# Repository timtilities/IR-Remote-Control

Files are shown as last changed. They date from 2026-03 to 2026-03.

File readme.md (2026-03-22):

I have a *Hunter* space heater whose remote control had partially stopped working. The power and mode buttons no longer functioned. Rather than buying a new heater, I decided to take a crack at making a new remote control for it.

***

Some of the buttons still worked, so I setup a [simple IR receiver](https://github.com/Arduino-IRremote/Arduino-IRremote/blob/master/examples/ReceiveDemo/ReceiveDemo.ino) with an Arduino Nano to scan the working button codes. 

The design uses the ATTINY85 MCU and a matrix keypad with 12 buttons (although only 6 are in use for this).  Each button press fires an interrupt to wake the MCU and send the IR signal associated with the button. Once that completes, the MCU goes back into deep sleep. The circuit uses around 30mA while sending and <10nA when sleeping. Assuming 10 button presses per day (over only the winter months), the 2 AAA batteries *should* last more than [5 years](http://oregonembedded.com/batterycalc.htm).  I use NiMH rechargeable batteries removed at the end of each season, so if I have to recharge them once a year I'm happy.

Since I rarely order single PCBs, I designed it with 12 buttons to allow the PCBs to be used in future projects.

The battery clips are Keystone Electronics [55TR](https://www.keyelco.com/product.cfm/product_id/3970), available from [Mouser electronics](https://www.mouser.com/ProductDetail/534-55TR).

The Arduino sketch requires the following libraries:

- [IRremote](https://github.com/Arduino-IRremote/Arduino-IRremote/)
- [Keypad](https://github.com/Chris--A/Keypad)
- [PinChangeInterrupt](https://github.com/NicoHood/PinChangeInterrupt)

The pogo pin adapter is available here:

[https://github.com/timtilities/Pogo-Pin-ICSP-Adapter](https://github.com/timtilities/Pogo-Pin-ICSP-Adapter)

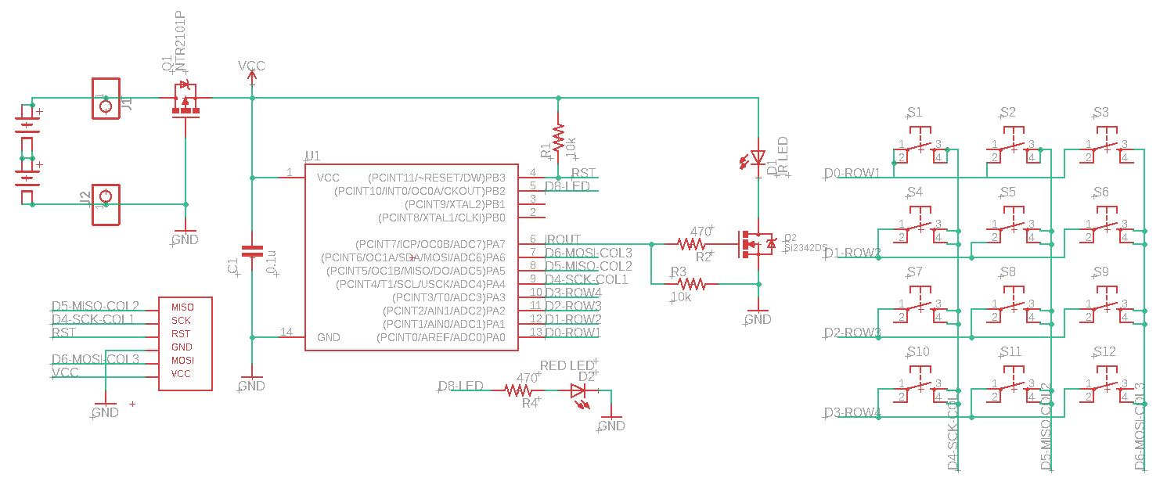
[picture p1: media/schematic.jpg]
schematic

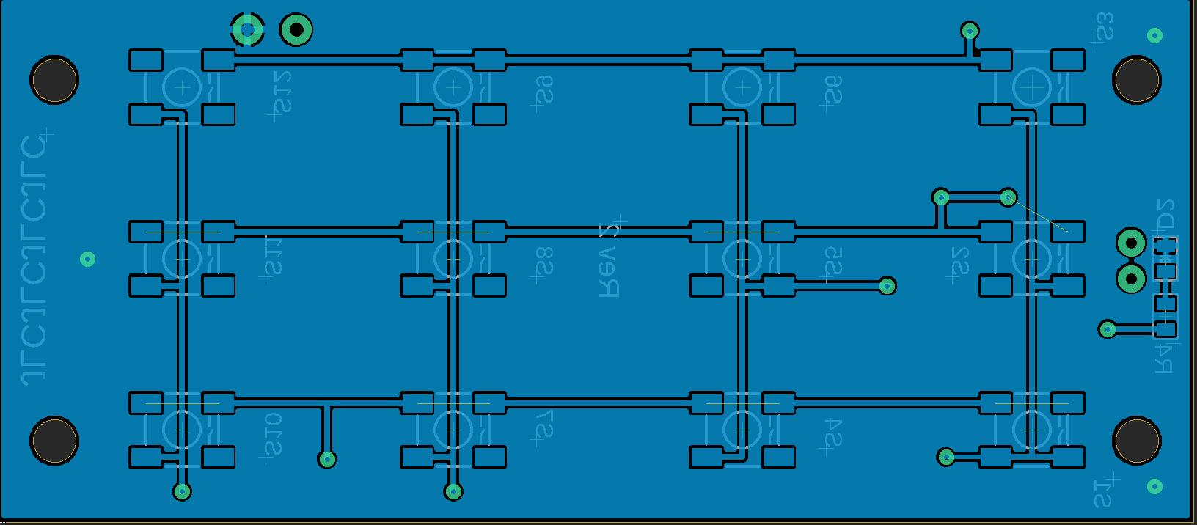
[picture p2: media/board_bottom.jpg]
board_bottom

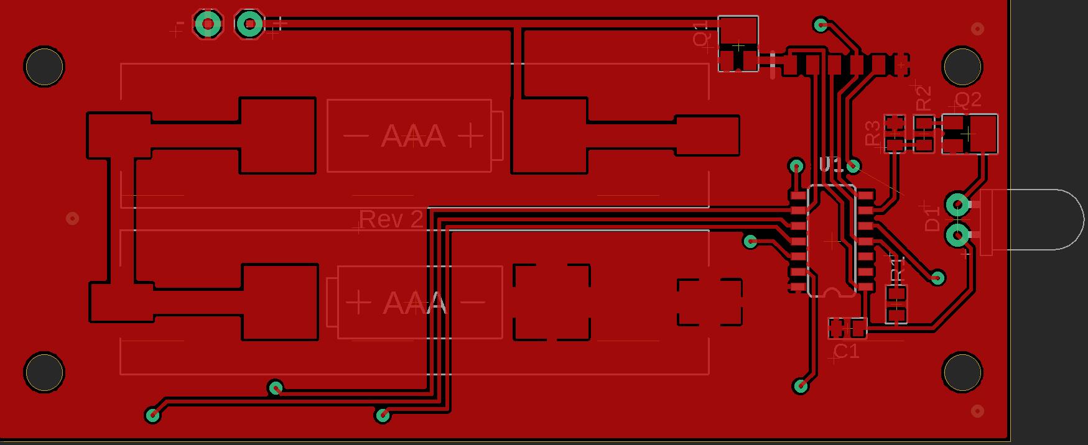
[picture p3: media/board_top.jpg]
board_top


The Case has been designed to be 3D printed, including multicolored buttons. I used the [Z-hop multi-colored printing method](https://www.youtube.com/watch?v=0Sla-vIsvh4) to print the buttons in multiple colors. The top and bottom snap together around the electronics, and the battery cover uses a tab/screw combination to secure it into place. The M3 knurled heat-set insert can be purchased [from Amazon](https://www.amazon.com/dp/B0BW1YP5VQ?psc=1&ref=ppx_yo2ov_dt_b_product_details).

There is an alternative bottom design without the battery cover. It simply snaps together with the top.

Some additional pics at various points in the design and assembly stages:

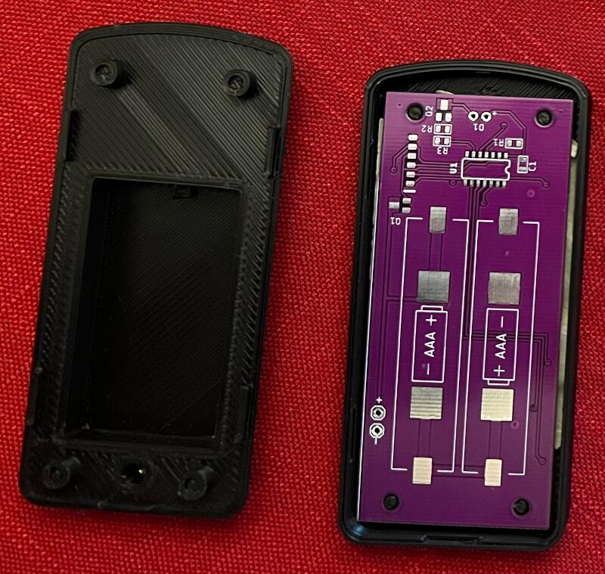
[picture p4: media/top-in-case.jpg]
top-in-case Raw PCB in partially assembled case

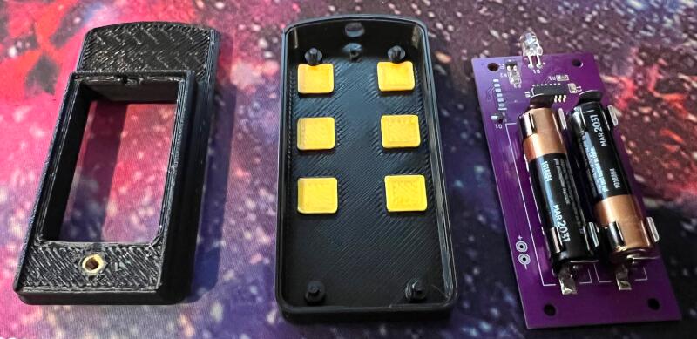
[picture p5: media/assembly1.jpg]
assembly1 PCB fully assembled and ready to be put in case

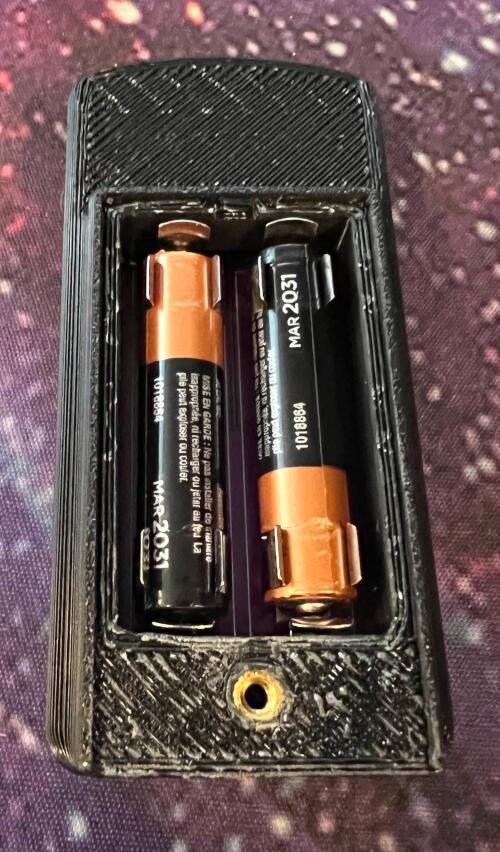
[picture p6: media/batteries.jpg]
batteries Fully assembled without battery cover

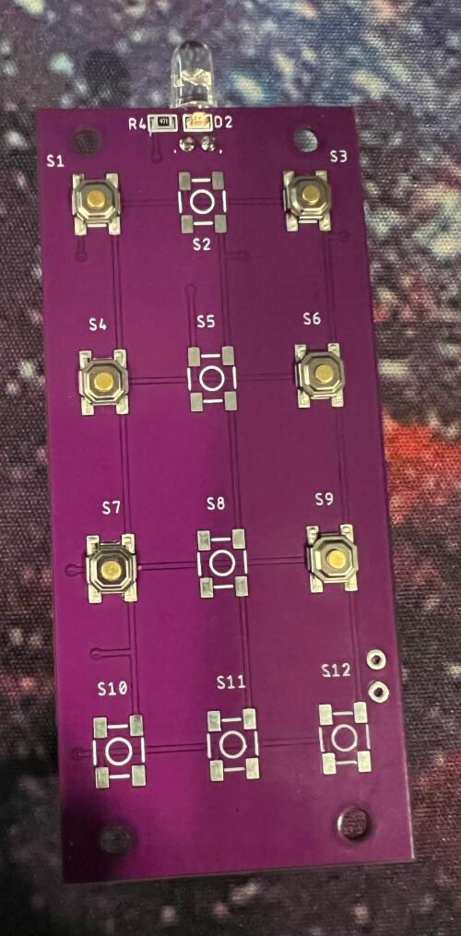
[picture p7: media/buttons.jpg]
buttons Bottom buttons

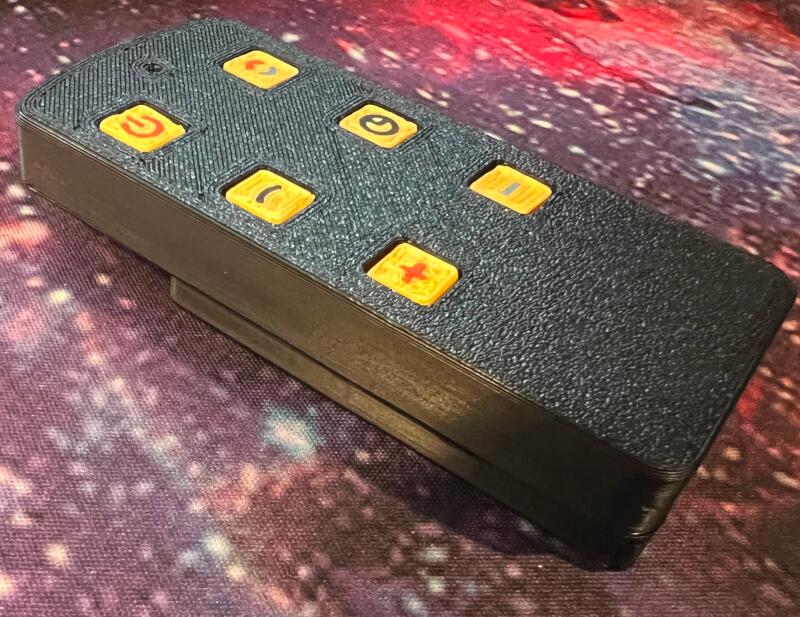
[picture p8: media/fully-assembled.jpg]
fully-assembled Fully assembled remote

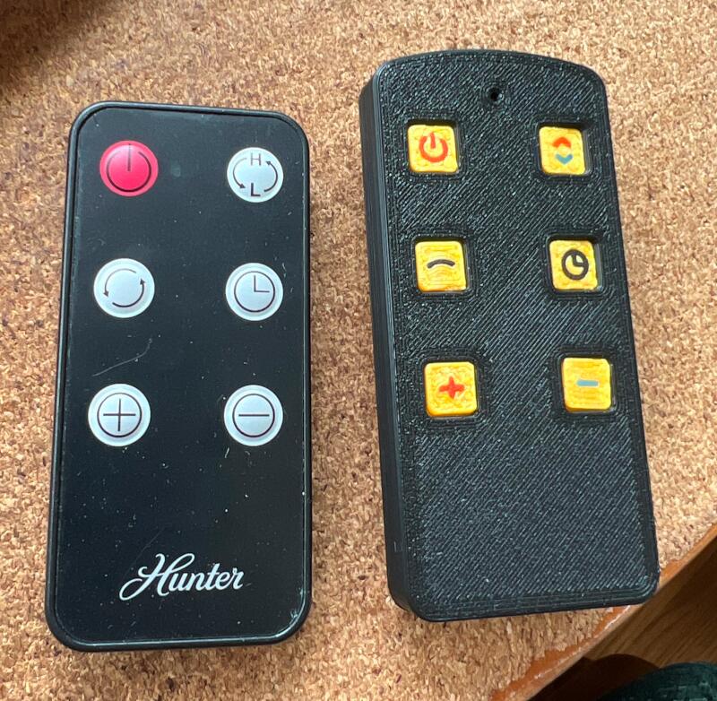
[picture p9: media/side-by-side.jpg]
side-by-side Side-by-side comparison

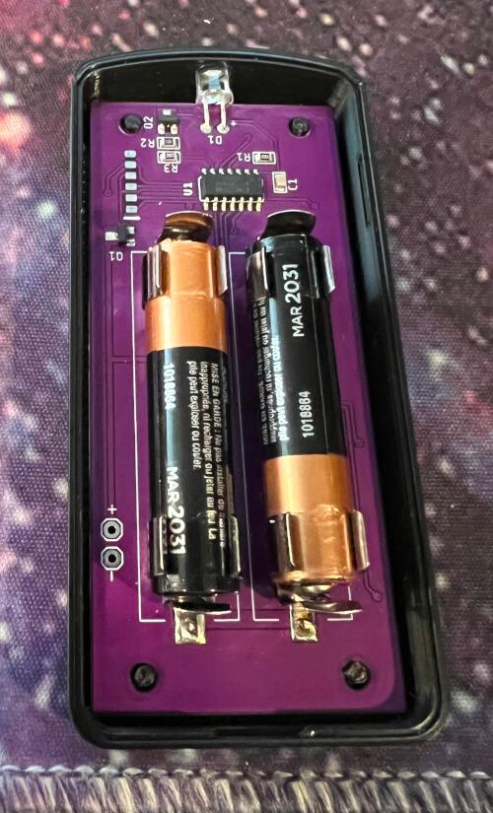
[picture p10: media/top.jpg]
top Top in case


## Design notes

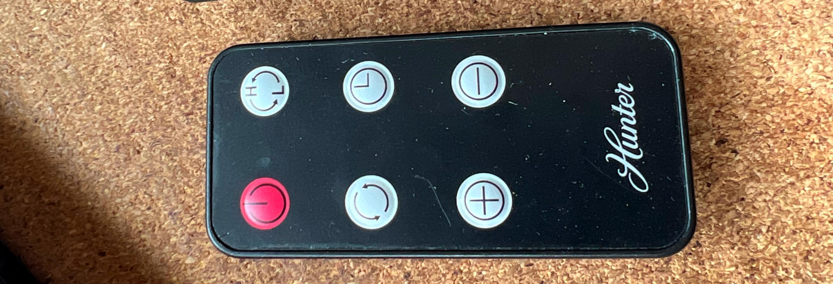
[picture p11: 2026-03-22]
media/hero-remote.jpg

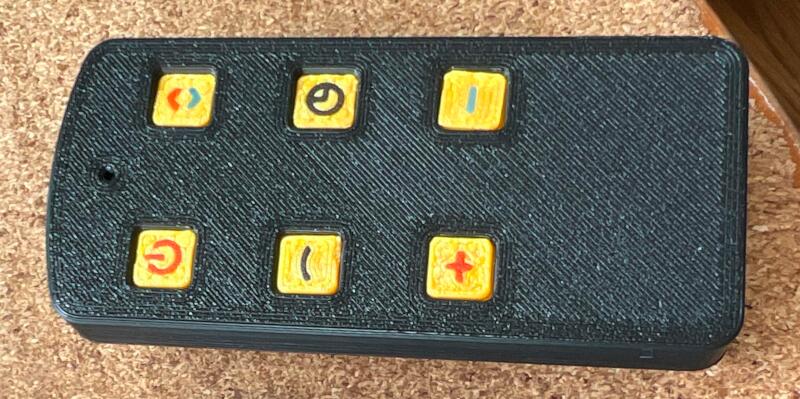
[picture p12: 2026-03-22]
media/remote-display.jpg

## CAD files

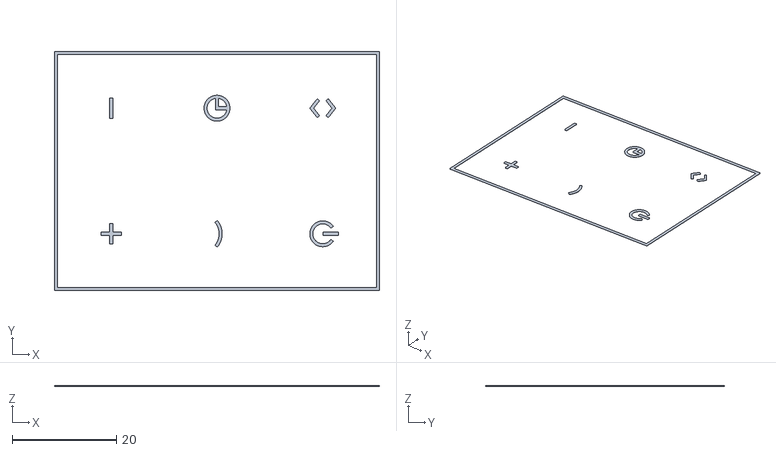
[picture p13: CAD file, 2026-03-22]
3dfiles/Buttons_Inlays.stl
62.4 x 45.9 x 0.24

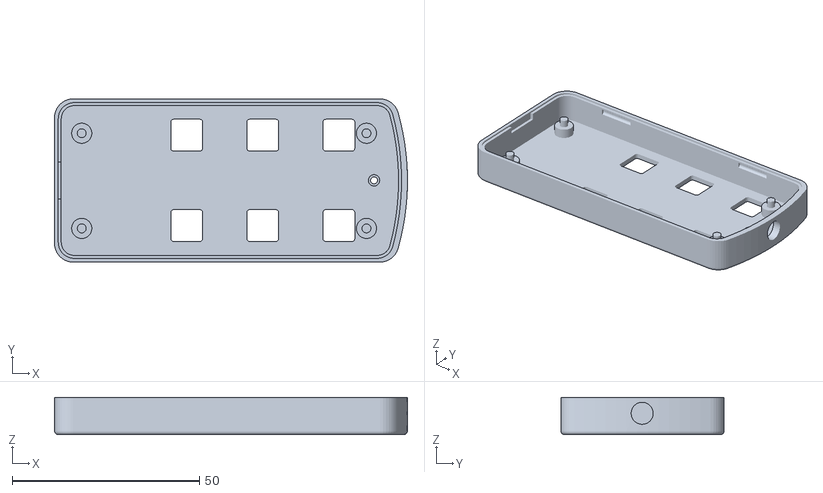
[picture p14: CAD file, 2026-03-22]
3dfiles/Top.stl
94.3 x 43.6 x 10.0

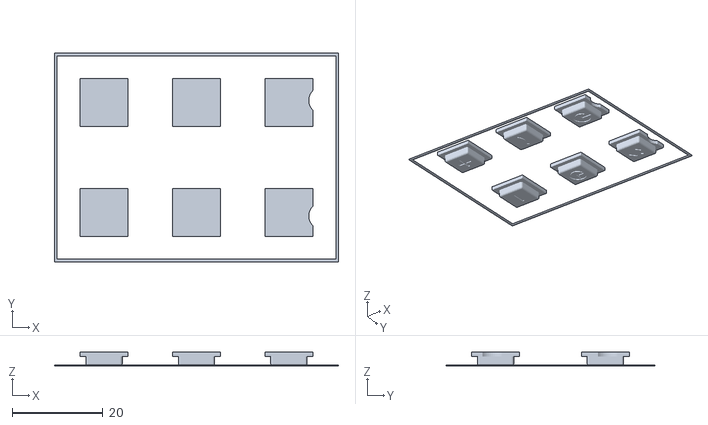
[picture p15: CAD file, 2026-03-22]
3dfiles/Buttons.stl
62.4 x 45.9 x 3.03

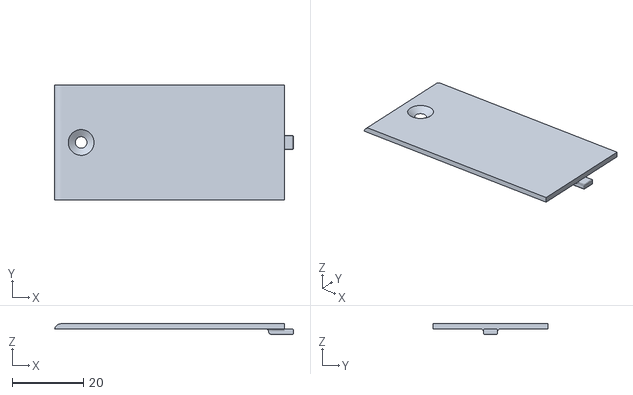
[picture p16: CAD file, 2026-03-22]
3dfiles/Battery Cover.stl
67.2 x 32.2 x 3.00

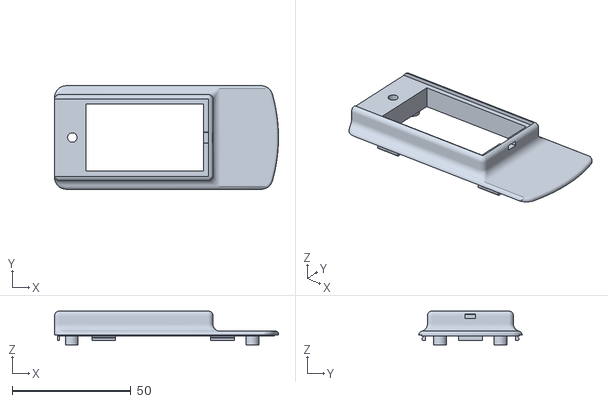
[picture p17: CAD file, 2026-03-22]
3dfiles/Bottom.stl
94.3 x 43.6 x 14.3

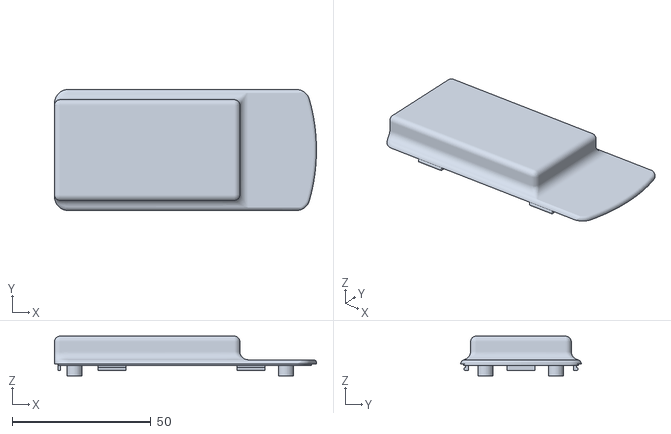
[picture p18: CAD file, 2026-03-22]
3dfiles/Bottom_No_Screw.stl
94.3 x 43.6 x 14.3

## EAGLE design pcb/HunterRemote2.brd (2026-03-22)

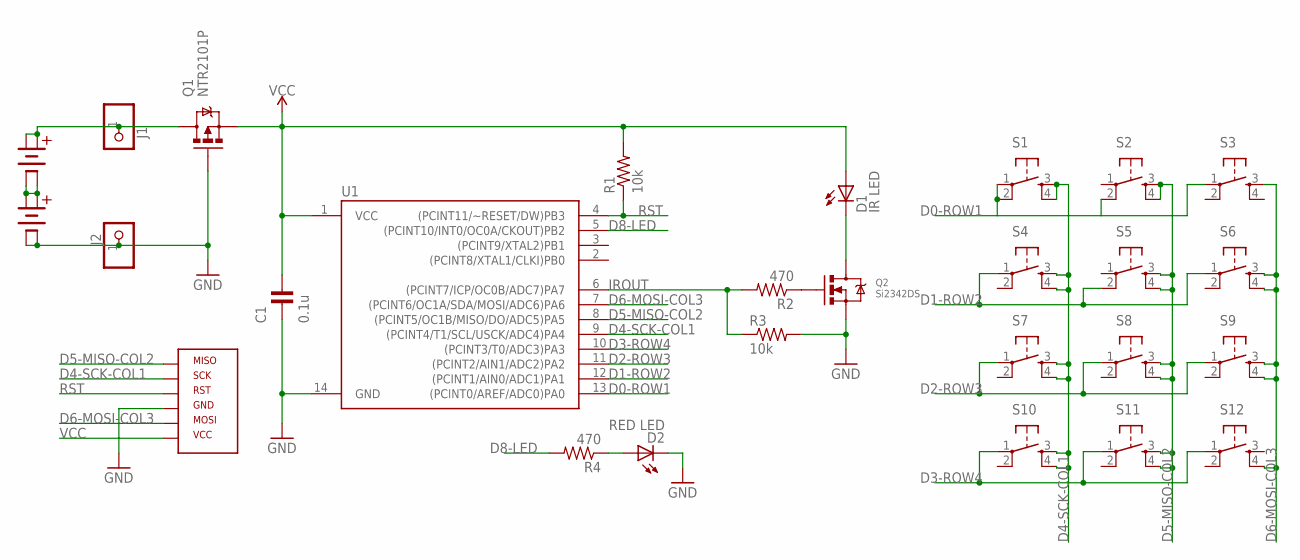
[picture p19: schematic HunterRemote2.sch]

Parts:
B1, B2: BATTERYAAA-KEYSTONE-55TR; KEYSTONE_55TR_AAA
C1: 0.1u; C0805
D1: IR LED; LED5MM-90
D2: RED LED; LED-0805-RED
J1, J2: PINHD-1X1; 1X01
Q1: NTR2101P; SOT23-3A
Q2: Si2342DS; SOT23-3A
R1, R3: 10k; R0805
R2, R4: 470; R0805
S1, S2, S3, S4, S5, S6, S7, S8, S9, S10, S11, S12: TAC_SWITCHSMD_5X5_LOW; TACTILE_SWITCH_SMD_5X5_LOW
U1: ATTINY84; SO14
U$1: AVR_ICSP_6PSTRAIGHT; AVR_ICSP_6P_SMD_V2

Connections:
D0-ROW1: S1.1, S1.2, S2.2, S3.1, U1.13 ((PCINT0/AREF/ADC0)PA0)
D1-ROW2: S4.1, S5.2, S6.1, U1.12 ((PCINT1/AIN0/ADC1)PA1)
D2-ROW3: S7.1, S8.1, S9.1, U1.11 ((PCINT2/AIN1/ADC2)PA2)
D3-ROW4: S10.1, S11.1, S12.1, U1.10 ((PCINT3/T0/ADC3)PA3)
D4-SCK-COL1: S1.3, S1.4, S4.3, S4.4, S7.3, S7.4, S10.3, S10.4, U1.9 ((PCINT4/T1/SCL/USCK/ADC4)PA4), U$1.SCK
D5-MISO-COL2: S2.3, S2.4, S5.3, S5.4, S8.3, S8.4, S11.3, S11.4, U1.8 ((PCINT5/OC1B/MISO/DO/ADC5)PA5), U$1.MISO
D6-MOSI-COL3: S3.3, S6.3, S6.4, S9.3, S9.4, S12.4, U1.7 ((PCINT6/OC1A/SDA/MOSI/ADC6)PA6), U$1.MOSI
D8-LED: R4.2, U1.5 ((PCINT10/INT0/OC0A/CKOUT)PB2)
GND: B1.NEG1, B1.NEG2, C1.1, D2.C, J2.1, Q1.1 (G), Q2.2 (S), R3.2, U1.14 (GND), U$1.GND
IROUT: R2.2, R3.1, U1.6 ((PCINT7/ICP/OC0B/ADC7)PA7)
unnamed: B2.POS1, B2.POS2, J1.1, Q1.3 (D)
unnamed: Q2.1 (G), R2.1
unnamed: D1.C, Q2.3 (D)
unnamed: B1.POS1, B1.POS2, B2.NEG1, B2.NEG2
unnamed: D2.A, R4.1
RST: R1.1, U1.4 ((PCINT11/~RESET/DW)PB3), U$1.RST
VCC: C1.2, D1.A, Q1.2 (S), R1.2, U1.1 (VCC), U$1.VCC

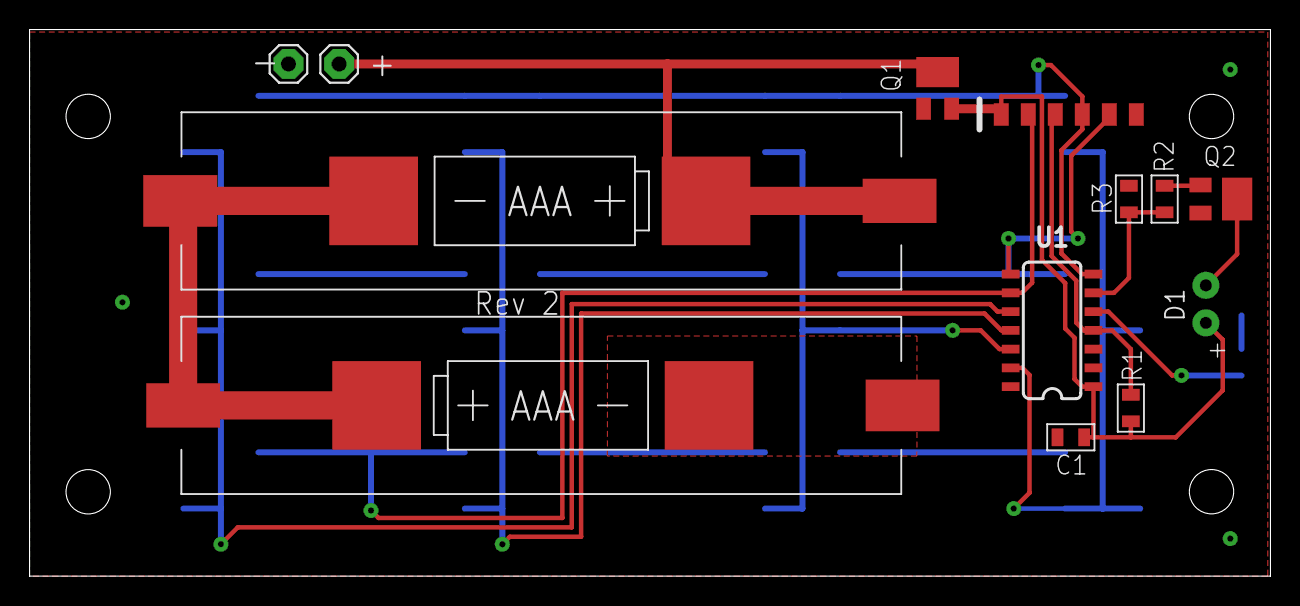
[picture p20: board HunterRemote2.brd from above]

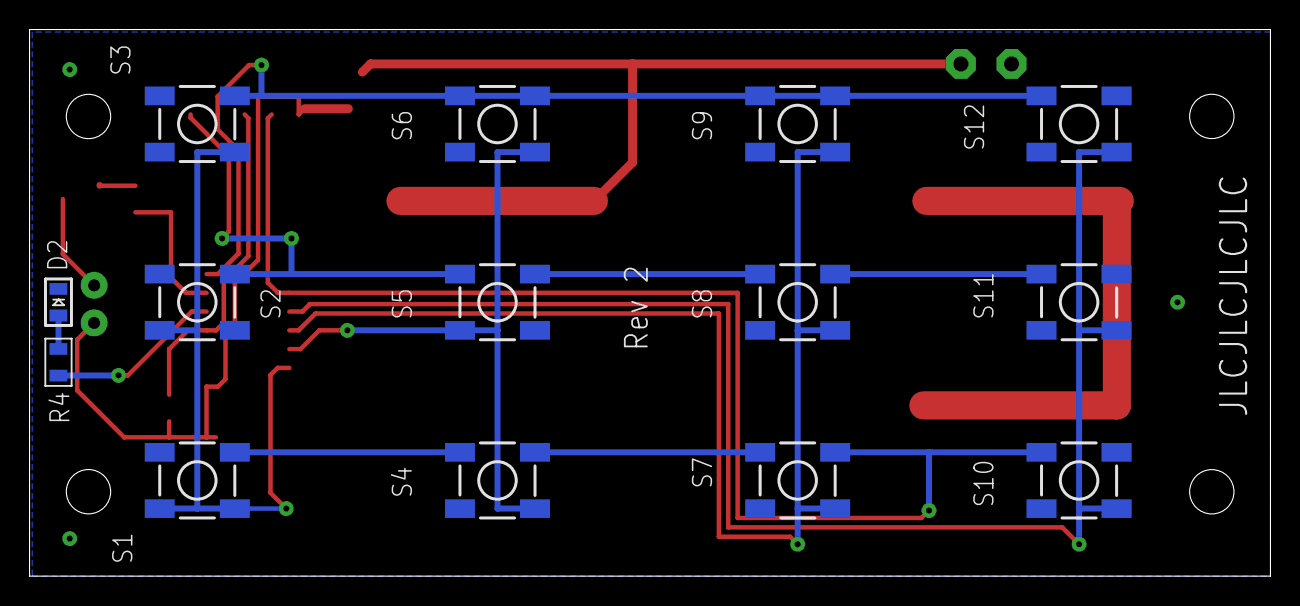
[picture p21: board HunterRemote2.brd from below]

Board: 2 copper layers, 84.0 x 37.0 mm, 27 parts (14 on the bottom side), 17 nets.

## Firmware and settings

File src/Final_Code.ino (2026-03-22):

/*
  This uses interrupts to wake from sleep, flash an LED, then go back to sleep... using a 3x4 keypad

  #### Keypad Setup ####
          7 - D6 (pin 7)	- Col 3
          6 - D5 (pin 8)	- Col 2
  Keypad  5 - D4 (pin 9) 	- Col 1
  Conn    4 - D3 (pin 10) 	- Row 4
          3 - D2 (pin 11) 	- Row 3
          2 - D1 (pin 12) 	- Row 2
          1 - D0 (pin 13) 	- Row 1
*/

#include "PinDefinitionsAndMore.h"  // Define macros for input and output pin etc.
/* These must be set BEFORE including IRremote.hpp! */
#define IR_SEND_PIN 7 // pin 6

/* Requirements:
*  https://github.com/Arduino-IRremote/Arduino-IRremote/
*  https://github.com/Chris--A/Keypad
*  https://github.com/NicoHood/PinChangeInterrupt  
*/
#include <TinyIRSender.hpp>
#include <avr/sleep.h>
#include <Keypad.h>
#include "PinChangeInterrupt.h"

/* number of items in an array */
#define NUMITEMS(arg) ((unsigned int) (sizeof (arg) / sizeof (arg [0])))

/* LED pin */
#define LED 8
/* How long should LED stay on after sending IR signals */
#define LED_WAIT 100

/* Initialize keypad matrix variables */
const byte ROWS = 4; 
const byte COLS = 3; 
char hexaKeys[] = {
  "123"
  "456"
  "789"
  "*0#"
};
byte rowPins[ROWS] = {0, 1, 2, 3}; 
byte colPins[COLS] = {4, 5, 6}; 
/* This must be done from loop() to avoid interrupt issues */
/* Keypad customKeypad = Keypad(makeKeymap(hexaKeys), rowPins, colPins, ROWS, COLS); */

/* Initialize a callback variable */
byte Pressed = 0;

void setup() {
  /* set ROW pins to input with a pullup */
  for (byte i = 0; i < NUMITEMS (rowPins); i++){
    pinMode (rowPins[i], INPUT_PULLUP);
  }
  
  /* Initialize LED pin */
  pinMode(LED, OUTPUT);
  digitalWrite(LED, LOW);

  /* Attach the new PinChangeInterrupt and enable event function below */
  for (byte i = 0; i < NUMITEMS (rowPins); i++){
    attachPCINT(digitalPinToPCINT(rowPins[i]), WakeUp, CHANGE);
  }

  /* ATTiny84 sleep */
  ADCSRA &= ~(1<<ADEN);			// Disable ADC
  PRR = 1<<PRUSI | 1<<PRADC;	// Turn off clocks to unused peripherals
  set_sleep_mode(SLEEP_MODE_PWR_DOWN);
}

void WakeUp(void) {
  Pressed = 1;
}

void loop() {
  /* Initialize IRCode */
  uint8_t IRCode;

  if (Pressed == 1){
    /* Restore Keypad operation after wake */
    for (byte i = 0; i < NUMITEMS (rowPins); i++){
      pinMode (rowPins[i], INPUT_PULLUP);
    }
    for (byte i = 0; i < NUMITEMS (colPins); i++){
      pinMode (colPins[i], INPUT_PULLUP);
    }

    /* Initialize Keypad class - this must be done here (rather than in setup) to avoid interrupt issues) */
    Keypad customKeypad = Keypad(makeKeymap(hexaKeys), rowPins, colPins, ROWS, COLS);
    
	/* Determine which button was pressed and send appropriate IR commands */
    /*char KeyPressed = customKeypad.getKey(); */
    switch (customKeypad.getKey()) {
      case '1':
        IRCode = 0xC;
        break;
      /*case '2':
        IRCode = 0x??;
        break;*/
      case '3':
        IRCode = 0x8;
        break;
      case '4':
        IRCode = 0x7;
        break;
      /*case '5':
        IRCode = 0x??;
        break;*/
      case '6':
        IRCode = 0x6;
        break;
      case '7':
        IRCode = 0x1C;
        break;
      /*case '8':
        IRCode = 0x??;
        break;*/
      case '9':
        digitalWrite(LED, HIGH);
        IRCode = 0x15;
        break;
      /*case '0':
        IRCode = 0x??;
        break;
      case '*':
        IRCode = 0x??;
        break;
      case '#':
        IRCode = 0x??;
        break;
      case 'A':
        IRCode = 0x??;
        break;
      case 'B':
        IRCode = 0x??;
        break;
      case 'C':
        IRCode = 0x??;
        break;
      case 'D':
        IRCode = 0x??;
        break;*/
      default: /* Keypress was not recognized/invalid */
        IRCode = 0;
    }
    if (IRCode != 0){
      digitalWrite(LED, HIGH);
      sendNEC(IR_SEND_PIN, 0xCF10, IRCode, 0);
      delay(LED_WAIT);
      digitalWrite(LED, LOW);
    }
  }  

  /* Clear callback variable */
  Pressed = 0;

  /* debounce */
  delay(100);
  
  /* Reset pins for interrupts */
  for (byte i = 0; i < NUMITEMS (rowPins); i++){
    pinMode (rowPins[i], INPUT_PULLUP);
  }
  for (byte i = 0; i < NUMITEMS (colPins); i++){
    pinMode (colPins[i], OUTPUT); digitalWrite (colPins[i], LOW);
  }
    
  /* Going to sleep */
  sleep_enable();
  set_sleep_mode(SLEEP_MODE_PWR_DOWN);//Setting the sleep mode, in our case full sleep
  sleep_cpu();
}

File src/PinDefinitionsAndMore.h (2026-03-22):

/*
 *  PinDefinitionsAndMore.h
 *
 *  Contains pin definitions for IRremote examples for various platforms
 *  as well as definitions for feedback LED and tone() and includes
 *
 *  Copyright (C) 2021-2022  Armin Joachimsmeyer
 *  armin.joachimsmeyer@gmail.com
 *
 *  This file is part of IRremote https://github.com/Arduino-IRremote/Arduino-IRremote.
 *
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
 */

/*
 * Pin mapping table for different platforms
 *
 * Platform     IR input    IR output   Tone      Core/Pin schema
 * --------------------------------------------------------------
 * DEFAULT/AVR  2           3           4         Arduino
 * ATtinyX5     0|PB0       4|PB4       3|PB3     ATTinyCore
 * ATtiny167    3|PA3       2|PA2       7|PA7     ATTinyCore
 * ATtiny167    9|PA3       8|PA2       5|PA7     Digispark pro
 * ATtiny3217  18|PA1      19|PA2      20|PA3     MegaTinyCore
 * ATtiny1604   2           3|PA5       %
 * ATtiny816   14|PA1      16|PA3       1|PA5     MegaTinyCore
 * ATtiny1614   8|PA1      10|PA3       1|PA5     MegaTinyCore
 * SAMD21       3           4           5
 * ESP8266      14|D5       12|D6       %
 * ESP32        15          4           27
 * BluePill     PA6         PA7         PA3
 * APOLLO3      11          12          5
 * RP2040       3|GPIO15    4|GPIO16    5|GPIO17
 */
//#define _IR_MEASURE_TIMING // For debugging purposes.

#if defined(__AVR__)
#if defined(__AVR_ATtiny25__) || defined(__AVR_ATtiny45__) || defined(__AVR_ATtiny85__) // Digispark board
#include "ATtinySerialOut.hpp" // TX is at pin 2 - Available as Arduino library "ATtinySerialOut". Saves 700 bytes program memory and 70 bytes RAM for ATtinyCore
#define IR_RECEIVE_PIN  0
#define IR_SEND_PIN     4 // Pin 2 is serial output with ATtinySerialOut. Pin 1 is internal LED and Pin3 is USB+ with pullup on Digispark board.
#define TONE_PIN        3
#define _IR_TIMING_TEST_PIN 3

#  elif defined(__AVR_ATtiny87__) || defined(__AVR_ATtiny167__) // Digispark pro board
#include "ATtinySerialOut.hpp" // Available as Arduino library "ATtinySerialOut"
// For ATtiny167 Pins PB6 and PA3 are usable as interrupt source.
#  if defined(ARDUINO_AVR_DIGISPARKPRO)
#define IR_RECEIVE_PIN   9 // PA3 - on Digispark board labeled as pin 9
//#define IR_RECEIVE_PIN  14 // PB6 / INT0 is connected to USB+ on DigisparkPro boards
#define IR_SEND_PIN      8 // PA2 - on Digispark board labeled as pin 8
#define TONE_PIN         5 // PA7 - on Digispark board labeled as pin 5
#define _IR_TIMING_TEST_PIN 10 // PA4
#  else
#define IR_RECEIVE_PIN  3 // PA3 - on Digispark board labeled as pin 9
#define IR_SEND_PIN     2 // PA2 - on Digispark board labeled as pin 8
#define TONE_PIN        7 // PA7 - on Digispark board labeled as pin 5
#  endif

#  elif defined(__AVR_ATtiny88__) // MH-ET Tiny88 board
#include "ATtinySerialOut.hpp" // Available as Arduino library "ATtinySerialOut". Saves 128 bytes program memory
// Pin 6 is TX pin 7 is RX
#define IR_RECEIVE_PIN   3 // INT1
#define IR_SEND_PIN      4
#define TONE_PIN         9
#define _IR_TIMING_TEST_PIN 8

#  elif defined(__AVR_ATtiny1616__)  || defined(__AVR_ATtiny3216__) || defined(__AVR_ATtiny3217__) // Tiny Core Dev board
#define IR_RECEIVE_PIN  18
#define IR_SEND_PIN     19
#define TONE_PIN        20
#define APPLICATION_PIN  0 // PA4
#undef LED_BUILTIN         // No LED available on the TinyCore 32 board, take the one on the programming board which is connected to the DAC output
#define LED_BUILTIN      2 // PA6

#  elif defined(__AVR_ATtiny816__) // Tiny Core Micro
#define IR_RECEIVE_PIN  14 // PA1
#define IR_SEND_PIN     16 // PA3
#define TONE_PIN         1 // PA5
#define APPLICATION_PIN  0 // PA4
#undef LED_BUILTIN         // No LED available, take the one which is connected to the DAC output
#define LED_BUILTIN      4 // PB5

#  elif defined(__AVR_ATtiny1614__)
#define IR_RECEIVE_PIN   8 // PA1
#define IR_SEND_PIN     10 // PA3
#define TONE_PIN         1 // PA5
#define APPLICATION_PIN  0 // PA4

#  elif defined(__AVR_ATtiny1604__)
#define IR_RECEIVE_PIN   2 // To be compatible with interrupt example, pin 2 is chosen here.
#define IR_SEND_PIN      3
#define APPLICATION_PIN  5

#define tone(...) void()      // Define as void, since TCB0_INT_vect is also used by tone()
#define noTone(a) void()
#define TONE_PIN        42 // Dummy for examples using it
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

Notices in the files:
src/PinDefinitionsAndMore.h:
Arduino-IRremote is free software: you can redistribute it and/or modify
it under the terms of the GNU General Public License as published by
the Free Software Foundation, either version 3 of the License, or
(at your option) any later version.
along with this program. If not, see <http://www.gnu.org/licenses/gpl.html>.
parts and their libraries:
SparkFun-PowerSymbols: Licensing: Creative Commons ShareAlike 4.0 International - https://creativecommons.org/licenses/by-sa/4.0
